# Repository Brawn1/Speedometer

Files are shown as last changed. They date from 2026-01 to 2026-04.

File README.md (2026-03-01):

# Hot Wheels Speedometer

Arduino Nano basierter Geschwindigkeitsmesser fuer Hot Wheels Strecken. Zwei IR-Sensoren im Abstand von 10 cm messen die Durchfahrtszeit und ein Servomotor zeigt die Geschwindigkeit auf einer analogen Skala an.

## Features

- Geschwindigkeitsmessung ueber zwei IR-Sensoren (10 cm Abstand)
- Analoge Tacho-Anzeige mit Servomotor
- Einstellbarer Servo-Ausschlag ueber 4 DIP-Switches (Multiplikator 1.0x - 5.0x)
- Batterieueberwachung mit Rot/Gruen LED (3.7V Li-Ion Akku)
- Sensor-Status LEDs (zeigen Sensor 1/2 Ausloesung an)
- Startup-Melodie ueber Piezo-Lautsprecher
- Serial Monitor Ausgabe fuer Debugging (9600 Baud)

## Hardware

### Komponenten

| Komponente | Anzahl |
|---|---|
| Arduino Nano | 1 |
| IR-Sensor (digital) | 2 |
| Servomotor | 1 |
| Piezo-Lautsprecher | 1 |
| 4-fach DIP-Switch | 1 |
| LED gruen (Batterie OK) | 1 |
| LED rot (Batterie niedrig) | 1 |
| LED (Sensor 1 Status) | 1 |
| LED (Sensor 2 Status) | 1 |
| Widerstand 10k Ohm | 2 |
| 3.7V Li-Ion Akku | 1 |

### Pin-Belegung

| Pin | Funktion |
|---|---|
| D2 | IR-Sensor 1 (Start) |
| D3 | IR-Sensor 2 (Ziel) |
| D4 | LED gruen (Batterie OK) |
| D5 | LED rot (Batterie niedrig) |
| D6 | LED Sensor 1 |
| D7 | LED Sensor 2 |
| D8 | Piezo-Lautsprecher |
| D9 | Servomotor |
| D10 | DIP-Switch 1 (Wert 1) |
| D11 | DIP-Switch 2 (Wert 2) |
| D12 | DIP-Switch 3 (Wert 4) |
| D13 | DIP-Switch 4 (Wert 8) |
| A0 | Batteriespannung (Spannungsteiler) |

### Spannungsteiler (Batteriemessung)

Die Batteriespannung wird ueber einen Spannungsteiler mit 2x 10k Ohm Widerstaenden gemessen. Der Spannungsteiler halbiert die Batteriespannung, damit sie im ADC-Messbereich des Arduino liegt.

```
Batterie+ ---[R1 10k]---+---[R2 10k]--- GND
                         |
                         A0
```

### DIP-Switch Anschluss

Die DIP-Switches nutzen die internen Pull-Up Widerstaende des Arduino. Jeder Schalter verbindet den Pin mit GND wenn aktiv.

```
Pin D10-D13 ---[DIP-Switch]--- GND
```

## DIP-Switch Multiplikator-Tabelle

Die 4 DIP-Switches steuern den Servo-Ausschlag mit 16 Stufen:

| DIP 4-3-2-1 | Wert | Multiplikator |
|---|---|---|
| 0000 | 0 | 1.0x |
| 0001 | 1 | 1.27x |
| 0010 | 2 | 1.53x |
| 0011 | 3 | 1.8x |
| 0100 | 4 | 2.07x |
| 0101 | 5 | 2.33x |
| 0110 | 6 | 2.6x |
| 0111 | 7 | 2.87x |
| 1000 | 8 | 3.13x |
| 1001 | 9 | 3.4x |
| 1010 | 10 | 3.67x |
| 1011 | 11 | 3.93x |
| 1100 | 12 | 4.2x |
| 1101 | 13 | 4.47x |
| 1110 | 14 | 4.73x |
| 1111 | 15 | 5.0x |

## Batterieueberwachung

| Spannung | Status | LED |
|---|---|---|
| > 3.6V | OK | Gruen |
| 3.4V - 3.6V | Niedrig | Rot |
| < 3.4V | Schwach | Rot |

Die Batterie wird alle 30 Sekunden geprueft. Die Messung erfolgt mit 16-fachem Oversampling fuer stabile Werte und wird nur durchgefuehrt wenn der Servo nicht aktiv ist.

## Messablauf

1. Einschalten: Startup-Melodie, Servo faehrt auf Startposition, Batterie wird geprueft
2. Auto faehrt durch Sensor 1: LED Sensor 1 leuchtet, Messung startet
3. Auto faehrt durch Sensor 2: LED Sensor 2 leuchtet, Geschwindigkeit wird berechnet
4. Servo zeigt Geschwindigkeit an (2 Sekunden)
5. Servo faehrt zurueck, beide Sensor-LEDs erlischen
6. Bereit fuer naechste Messung

Bei Timeout (Sensor 2 nicht innerhalb von 4 Sekunden ausgeloest) wird die Messung abgebrochen.

## Projektstruktur

```
Speedometer/
├── Code/speedometer/speedometer.ino   # Arduino Sketch
├── Kicad/                             # KiCad Schaltplan
├── Case/                              # Gehaeuse (FreeCAD)
├── LICENSE
└── README.md
```

## Lizenz

Siehe [LICENSE](LICENSE).

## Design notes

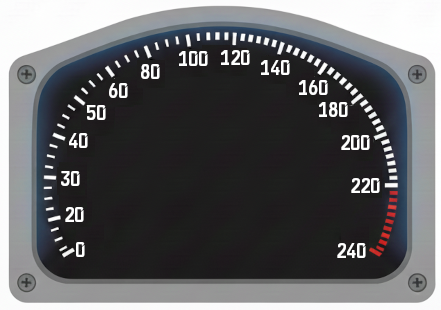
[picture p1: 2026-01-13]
Case/Tacho.png

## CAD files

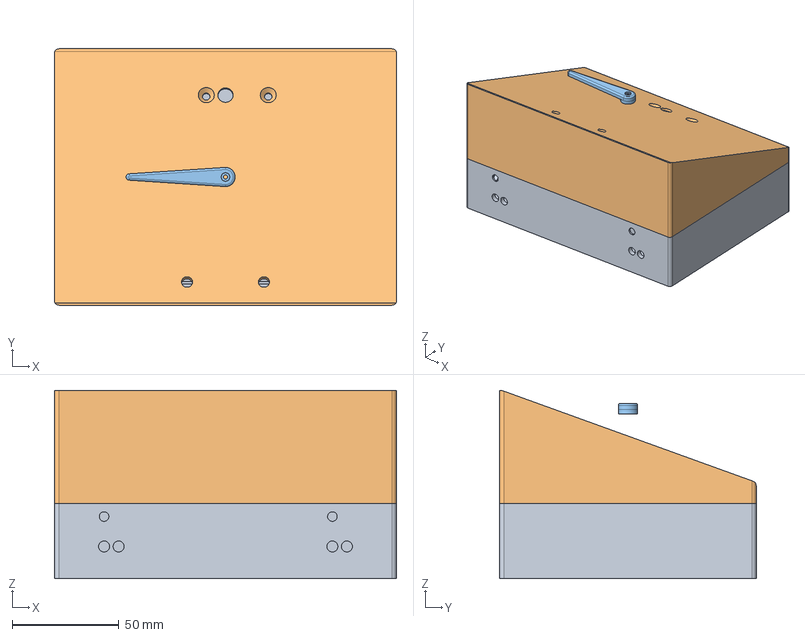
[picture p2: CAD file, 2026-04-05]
Case/speedometer.FCStd
160.0 x 120.0 x 88.0 mm
Bottom
Top
Tacho_Needle

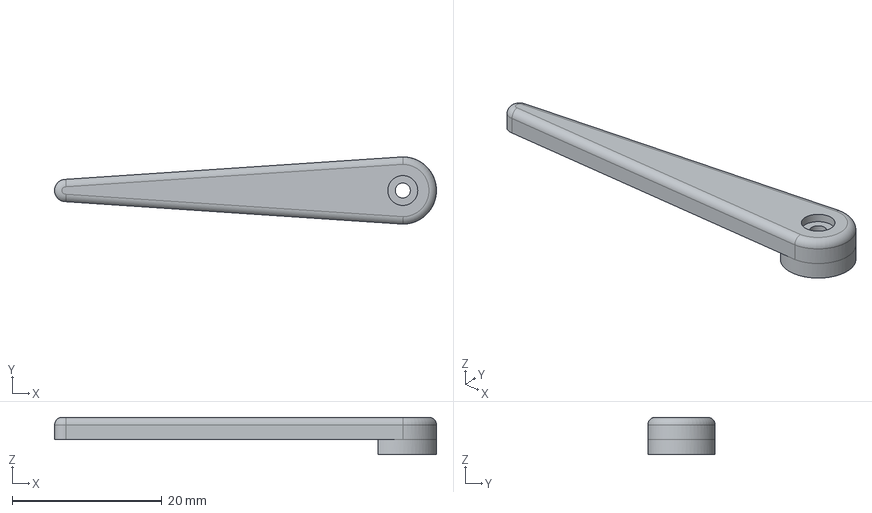
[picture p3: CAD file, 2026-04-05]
Case/Tacho_Needle.step
51.0 x 9.00 x 5.00 mm

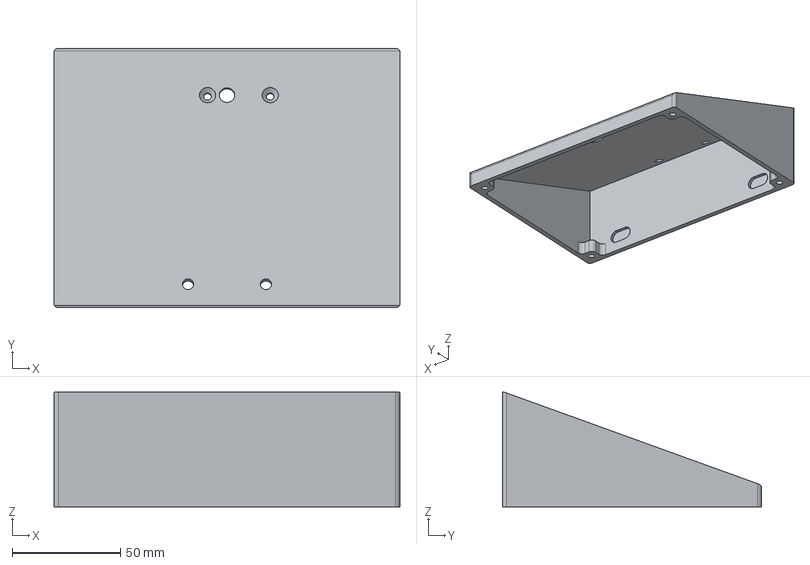
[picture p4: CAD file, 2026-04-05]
Case/Top.step
160.0 x 120.0 x 53.0 mm

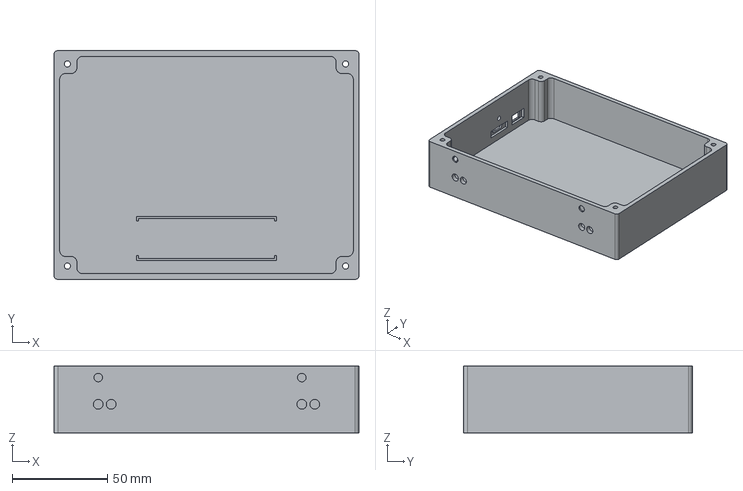
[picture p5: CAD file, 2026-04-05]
Case/Bottom.step
160.0 x 120.0 x 35.0 mm

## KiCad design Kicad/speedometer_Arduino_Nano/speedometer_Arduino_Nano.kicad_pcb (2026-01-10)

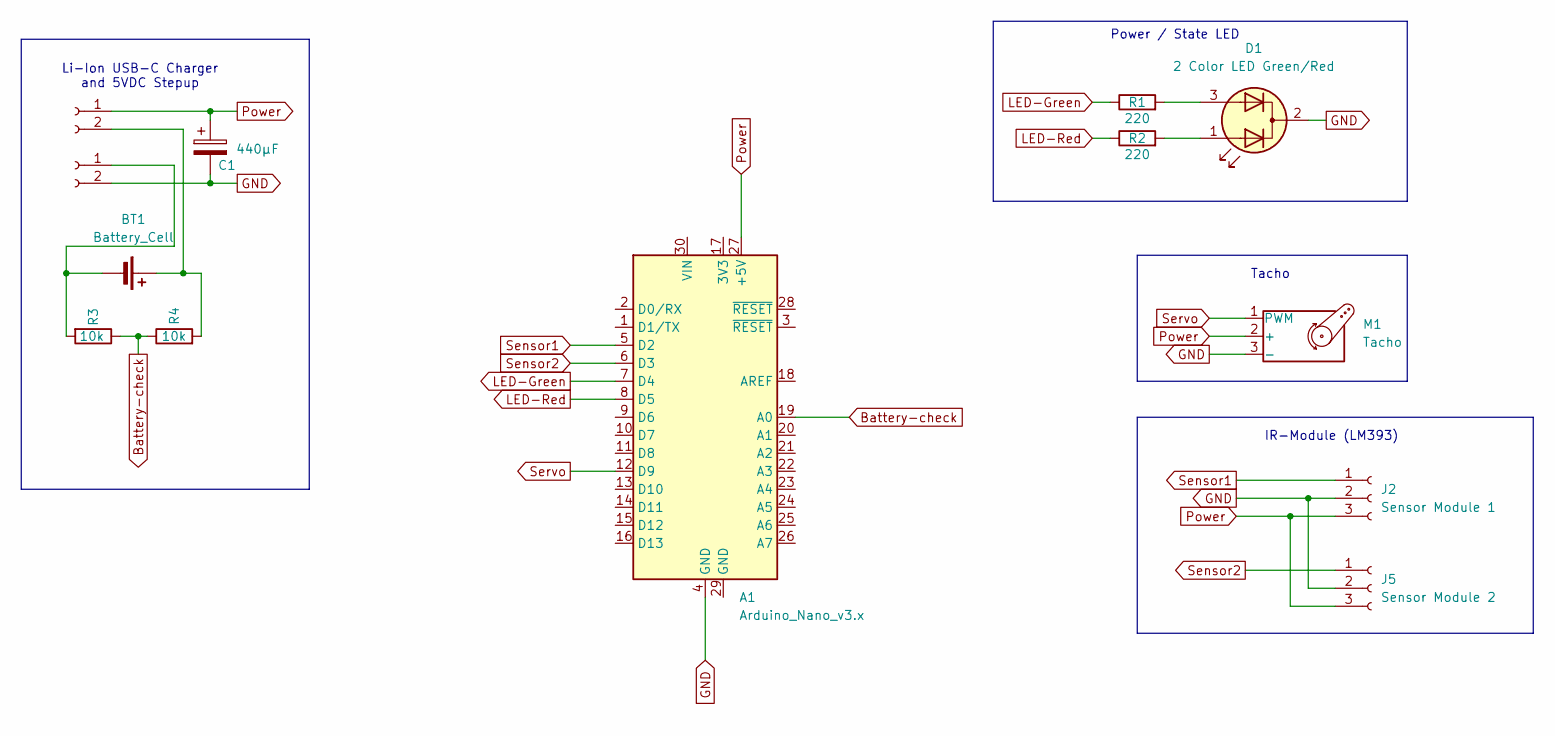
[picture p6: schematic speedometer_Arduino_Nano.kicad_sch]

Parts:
A1: Arduino_Nano_v3.x; Arduino_Nano
BT1: Battery_Cell; BatteryHolder_Keystone_1042_1x18650
C1: 440µF; CP_Radial_D10.0mm_P5.00mm
D1: 2 Color LED Green/Red; LED_D5.0mm-3
J1, J3: Conn_01x02_Socket; PinSocket_1x02_P2.54mm_Vertical
J2: Sensor Module 1; PinHeader_1x03_P2.54mm_Vertical
J5: Sensor Module 2; PinHeader_1x03_P2.54mm_Vertical
M1: Tacho; PinHeader_1x03_P2.54mm_Vertical
R1, R2: 220; R_Axial_DIN0207_L6.3mm_D2.5mm_P10.16mm_Horizontal
R3, R4: 10k; R_Axial_DIN0207_L6.3mm_D2.5mm_P10.16mm_Horizontal

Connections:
Battery-check: A1.19 (A0), R3.1, R4.1
GND: A1.4 (GND), C1.2, D1.2 (K), J2.2, J3.2, J5.2, M1.3 (-)
LED-Green: A1.7 (D4), R1.1
LED-Red: A1.8 (D5), R2.1
unnamed: BT1.1 (+), J1.2, R4.2
unnamed: BT1.2 (-), J3.1, R3.2
unnamed: D1.1 (A1), R2.2
unnamed: D1.3 (A2), R1.2
Power: A1.27 (+5V), C1.1, J1.1, J2.3, J5.3, M1.2 (+)
Sensor1: A1.5 (D2), J2.1
Sensor2: A1.6 (D3), J5.1
Servo: A1.12 (D9), M1.1 (PWM)

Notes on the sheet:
IR-Module (LM393)
Power / State LED
Tacho
Li-Ion USB-C Charger and 5VDC Stepup

Board: 2 copper layers, 13 parts (0 on the bottom side), 12 nets, no tracks yet.

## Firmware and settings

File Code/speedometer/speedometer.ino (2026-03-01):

#include <Servo.h>

// Pin-Definitionen
const int SENSOR1_PIN = 2;  // Erster IR-Sensor (Digital Pin)
const int SENSOR2_PIN = 3;  // Zweiter IR-Sensor (Digital Pin)
const int SERVO_PIN = 9;    // Servo Motor Pin
const int BATTERY_PIN = A0; // Batterie-Spannungsmessung (Analog Pin)
const int LED_GREEN_PIN = 4; // Grüne LED
const int LED_RED_PIN = 5;   // Rote LED
const int LED_SENSOR1_PIN = 6; // LED Sensor 1
const int LED_SENSOR2_PIN = 7; // LED Sensor 2
const int PIEZO_PIN = 8;      // Piezo Lautsprecher
const int DIP1_PIN = 10;      // DIP-Switch 1 (Wert 1)
const int DIP2_PIN = 11;      // DIP-Switch 2 (Wert 2)
const int DIP3_PIN = 12;      // DIP-Switch 3 (Wert 4)
const int DIP4_PIN = 13;      // DIP-Switch 4 (Wert 8)

// Konstanten
const float DISTANCE_CM = 10.0;  // Abstand zwischen Sensoren in cm
const int SERVO_MIN_ANGLE = 20;   // Minimaler Servo-Winkel
const int SERVO_MAX_ANGLE = 170; // Maximaler Servo-Winkel
const float MAX_SPEED_KMH = 150.0; // Maximale erwartete Geschwindigkeit in km/h
const int DEBOUNCE_DELAY = 50; // Entprellzeit in Millisekunden
const int SERVO_MOVE_DELAY = 500; // Zeit in ms zum Erreichen der Servo-Position
// Multiplikator-Bereich für DIP-Switches (0000=1.0, 1111=5.0)
const float MULTI_MIN = 1.0;
const float MULTI_MAX = 5.0;


// Batterie-Konstanten
const float BATTERY_LOW_VOLTAGE = 3.4;  // Warnung bei 3.4V (Li-Ion fast leer)
const float BATTERY_WARN_VOLTAGE = 3.6; // Mittlerer Bereich - LED rot
const float BATTERY_FULL_VOLTAGE = 4.2; // Voll geladen
const unsigned long BATTERY_CHECK_INTERVAL = 30000; // Batterie alle 30 Sekunden prüfen
const float ADC_REFERENCE_VOLTAGE = 4.457; // Arduino Nano ADC Referenzspannung (gemessen: 4.457V DC)
const float ADC_MAX_VALUE = 1023.0;      // 10-bit ADC maximaler Wert (0-1023)
const float R1 = 10000.0; // 10k Widerstand
const float R2 = 10000.0; // 10k Widerstand
const int ADC_SAMPLES = 16; // Anzahl Messungen für Mittelwert



// Variablen
Servo speedServo;
unsigned long sensor1Time = 0;
unsigned long sensor2Time = 0;
bool sensor1Triggered = false;
bool measurementActive = false;
unsigned long lastSensor1Trigger = 0;
unsigned long lastSensor2Trigger = 0;
unsigned long lastBatteryCheck = 0;

void setup() {
  // Serial Monitor initialisieren
  Serial.begin(9600);
  Serial.println(F("Geschwindigkeitsmessung gestartet"));
  Serial.print(F("Sensorabstand: "));
  Serial.print(DISTANCE_CM, 0);
  Serial.println(F(" cm"));
  Serial.println(F("Entprellung aktiviert"));
  Serial.println(F("Battery-Monitoring aktiviert"));
  Serial.println(F("------------------------"));
  
  // Pins konfigurieren
  pinMode(SENSOR1_PIN, INPUT);
  pinMode(SENSOR2_PIN, INPUT);
  pinMode(LED_GREEN_PIN, OUTPUT);
  pinMode(LED_RED_PIN, OUTPUT);
  pinMode(LED_SENSOR1_PIN, OUTPUT);
  pinMode(LED_SENSOR2_PIN, OUTPUT);
  pinMode(DIP1_PIN, INPUT_PULLUP);
  pinMode(DIP2_PIN, INPUT_PULLUP);
  pinMode(DIP3_PIN, INPUT_PULLUP);
  pinMode(DIP4_PIN, INPUT_PULLUP);
  
  pinMode(PIEZO_PIN, OUTPUT);

  // Startup-Melodie abspielen
  playStartupMelody();

  // Servo initialisieren und zur Startposition bewegen
  resetServoToStartPosition();

  // Erste Batterie-Prüfung
  checkBattery();
}

void loop() {
  unsigned long currentTime = millis();
  
  // Batterie regelmäßig prüfen (nur wenn Servo nicht aktiv)
  if (!measurementActive && currentTime - lastBatteryCheck > BATTERY_CHECK_INTERVAL) {
    checkBattery();
    lastBatteryCheck = currentTime;
  }

  
  // Sensor 1 prüfen (Start der Messung) mit Entprellung
  if (digitalRead(SENSOR1_PIN) == LOW && !measurementActive) {
    if (currentTime - lastSensor1Trigger > DEBOUNCE_DELAY) {
      sensor1Time = currentTime;
      sensor1Triggered = true;
      measurementActive = true;
      lastSensor1Trigger = currentTime;
      digitalWrite(LED_SENSOR1_PIN, HIGH);
      Serial.println(F("Sensor 1 ausgelöst - Messung gestartet"));
    }
  }
  
  // Sensor 2 prüfen (Ende der Messung) mit Entprellung
  if (digitalRead(SENSOR2_PIN) == LOW && measurementActive && sensor1Triggered) {
    if (currentTime - lastSensor2Trigger > DEBOUNCE_DELAY) {
      sensor2Time = currentTime;
      lastSensor2Trigger = currentTime;
      digitalWrite(LED_SENSOR2_PIN, HIGH);

      // Zeit zwischen Sensoren berechnen
      unsigned long timeDiff = sensor2Time - sensor1Time;
      
      // Geschwindigkeit berechnen
      if (timeDiff > 0) {
        // Geschwindigkeit in cm/ms
        float speedCmPerMs = DISTANCE_CM / (float)timeDiff;
        
        // Umrechnung in km/h
        // cm/ms → m/s → km/h: cm/ms * 10 * 3.6 = cm/ms * 36
        float speedKmh = speedCmPerMs * 36.0;
        
        // Umrechnung in m/s
        // cm/ms → m/s: cm/ms * (1m/100cm) * (1000ms/1s) = cm/ms * 10
        float speedMs = speedCmPerMs * 10.0;
        
        // Ergebnisse ausgeben
        Serial.println(F("------------------------"));
        Serial.print(F("Zeit: "));
        Serial.print((timeDiff / 1000.0), 4);
        Serial.println(F(" s"));
        Serial.print(F("Geschwindigkeit: "));
        Serial.print(speedKmh, 2);
        Serial.print(F(" km/h ("));
        Serial.print(speedMs, 4);
        Serial.println(F(" m/s)"));
        Serial.println(F("------------------------"));
        
        // Servo-Position berechnen und setzen
        int servoAngle = calculateServoAngle(speedKmh);
        speedServo.attach(SERVO_PIN);  // Servo aktivieren vor dem Schreiben
        speedServo.write(servoAngle);
        Serial.print(F("Servo-Position: "));
        Serial.print(servoAngle);
        Serial.print(F("° (Multiplikator: "));
        Serial.print(readDipMultiplier(), 1);
        Serial.println(F(")"));
        Serial.println();
        
        // Servo 2 Sekunden anzeigen lassen
        delay(2000);
        
        // Zurück zur Startposition fahren und Servo deaktivieren
        resetServoToStartPosition();
      }

      // Sensor-LEDs ausschalten
      digitalWrite(LED_SENSOR1_PIN, LOW);
      digitalWrite(LED_SENSOR2_PIN, LOW);

      // Reset für nächste Messung
      sensor1Triggered = false;
      measurementActive = false;
      
      // Kurze Verzögerung um Mehrfachauslösungen zu vermeiden
      delay(500);
    }
  }
  
  // Timeout: Wenn Sensor 2 nicht innerhalb von 4 Sekunden ausgelöst wird
  if (measurementActive && (currentTime - sensor1Time > 4000)) {
    Serial.println(F("Timeout - Messung abgebrochen"));
    measurementActive = false;
    sensor1Triggered = false;
    digitalWrite(LED_SENSOR1_PIN, LOW);
    digitalWrite(LED_SENSOR2_PIN, LOW);
    resetServoToStartPosition();
  }
  
  delay(1);  // Kleine Verzögerung für Stabilität
}

// Startup-Melodie abspielen
void playStartupMelody() {
  // Aufsteigende Tonfolge
  tone(PIEZO_PIN, 523, 150);  // C5
  delay(180);
  tone(PIEZO_PIN, 659, 150);  // E5
  delay(180);
  tone(PIEZO_PIN, 784, 150);  // G5
  delay(180);
  tone(PIEZO_PIN, 1047, 300); // C6
  delay(350);
  noTone(PIEZO_PIN);
}

// Funktion zum Zurücksetzen des Servos zur Startposition und Deaktivieren
void resetServoToStartPosition() {
  speedServo.attach(SERVO_PIN);
  speedServo.write(SERVO_MIN_ANGLE);
  delay(SERVO_MOVE_DELAY);  // Zeit zum Erreichen der Position
  speedServo.detach();
}

// DIP-Switch Multiplikator auslesen (LOW = aktiv wegen INPUT_PULLUP)
float readDipMultiplier() {
  int dipValue = 0;
  if (digitalRead(DIP1_PIN) == LOW) dipValue += 1;
  if (digitalRead(DIP2_PIN) == LOW) dipValue += 2;
  if (digitalRead(DIP3_PIN) == LOW) dipValue += 4;
  if (digitalRead(DIP4_PIN) == LOW) dipValue += 8;
  // 0-15 linear auf MULTI_MIN-MULTI_MAX abbilden
  return MULTI_MIN + (dipValue / 15.0) * (MULTI_MAX - MULTI_MIN);
}

// Funktion zur Berechnung des Servo-Winkels basierend auf Geschwindigkeit
int calculateServoAngle(float speedKmh) {
  // Begrenze Geschwindigkeit auf Maximum
  if (speedKmh > MAX_SPEED_KMH) {
    speedKmh = MAX_SPEED_KMH;
  }

  // Lineare Abbildung von 0-MAX_SPEED_KMH auf SERVO_MIN_ANGLE-SERVO_MAX_ANGLE
  int angle = SERVO_MIN_ANGLE + (int)((speedKmh / MAX_SPEED_KMH) * (SERVO_MAX_ANGLE - SERVO_MIN_ANGLE));

  // Begrenze Winkel auf gültigen Bereich
  if (angle < SERVO_MIN_ANGLE) angle = SERVO_MIN_ANGLE;
  if (angle > SERVO_MAX_ANGLE) angle = SERVO_MAX_ANGLE;

  float multiplier = readDipMultiplier();
  return round(float(angle) * multiplier);
}

// Funktion zur Batterie-Spannungsmessung mit Mehrfach-Sampling
float readBatteryVoltage() {
  long sum = 0;
  // Erste Messung verwerfen (ADC-Kanal stabilisieren)
  analogRead(BATTERY_PIN);
  for (int i = 0; i < ADC_SAMPLES; i++) {
    sum += analogRead(BATTERY_PIN);
  }
  float avgValue = (float)sum / ADC_SAMPLES;
  float voltage_at_pin = (avgValue / ADC_MAX_VALUE) * ADC_REFERENCE_VOLTAGE;
  return voltage_at_pin * (R1 + R2) / R2;
}

// Funktion zur Batterie-Prüfung und LED-Steuerung
void checkBattery() {
  float voltage = readBatteryVoltage();

  // Debug-Ausgabe
  Serial.print(F("Batterie: "));
  Serial.print(voltage, 2);
  Serial.print(F("V"));

  // LED-Status setzen
  if (voltage < BATTERY_LOW_VOLTAGE) {
    // Batterie schwach - Rote LED dauerhaft
    digitalWrite(LED_GREEN_PIN, LOW);
    digitalWrite(LED_RED_PIN, HIGH);
    Serial.println(F(" - BATTERIE SCHWACH!"));
  } else if (voltage < BATTERY_WARN_VOLTAGE) {
    // Batterie mittel - Rote LED
    digitalWrite(LED_GREEN_PIN, LOW);
    digitalWrite(LED_RED_PIN, HIGH);
    Serial.println(F(" - BATTERIE NIEDRIG"));
  } else {
    // Batterie OK - Grüne LED
    digitalWrite(LED_GREEN_PIN, HIGH);
    digitalWrite(LED_RED_PIN, LOW);
    Serial.println(F(" - OK"));
  }
}

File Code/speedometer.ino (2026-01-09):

#include <Servo.h>

// Pin-Definitionen
const int SENSOR1_PIN = 2;  // Erster IR-Sensor (Digital Pin)
const int SENSOR2_PIN = 3;  // Zweiter IR-Sensor (Digital Pin)
const int SERVO_PIN = 9;    // Servo Motor Pin

// Konstanten
const float DISTANCE_CM = 10.0;  // Abstand zwischen Sensoren in cm
const int SERVO_MIN_ANGLE = 0;   // Minimaler Servo-Winkel
const int SERVO_MAX_ANGLE = 180; // Maximaler Servo-Winkel
const float MAX_SPEED_KMH = 20.0; // Maximale erwartete Geschwindigkeit in km/h

// Variablen
Servo speedServo;
unsigned long sensor1Time = 0;
unsigned long sensor2Time = 0;
bool sensor1Triggered = false;
bool measurementActive = false;

void setup() {
  // Serial Monitor initialisieren
  Serial.begin(9600);
  Serial.println("Geschwindigkeitsmessung gestartet");
  Serial.println("Sensorabstand: 10cm");
  Serial.println("------------------------");
  
  // Pins konfigurieren
  pinMode(SENSOR1_PIN, INPUT);
  pinMode(SENSOR2_PIN, INPUT);
  
  // Servo initialisieren
  speedServo.attach(SERVO_PIN);
  speedServo.write(0);  // Servo auf 0° setzen
  
  delay(1000);
}

void loop() {
  // Sensor 1 prüfen (Start der Messung)
  if (digitalRead(SENSOR1_PIN) == LOW && !measurementActive) {
    sensor1Time = millis();
    sensor1Triggered = true;
    measurementActive = true;
    Serial.println("Sensor 1 ausgelöst - Messung gestartet");
  }
  
  // Sensor 2 prüfen (Ende der Messung)
  if (digitalRead(SENSOR2_PIN) == LOW && measurementActive && sensor1Triggered) {
    sensor2Time = millis();
    
    // Zeit zwischen Sensoren berechnen
    unsigned long timeDiff = sensor2Time - sensor1Time;
    
    // Geschwindigkeit berechnen
    if (timeDiff > 0) {
      // Geschwindigkeit in cm/ms
      float speedCmPerMs = DISTANCE_CM / (float)timeDiff;
      
      // Umrechnung in km/h
      float speedKmh = speedCmPerMs * 3600.0;
      
      // Umrechnung in m/s
      float speedMs = speedCmPerMs * 10.0;
      
      // Ergebnisse ausgeben
      Serial.println("------------------------");
      Serial.print("Zeit: ");
      Serial.print(timeDiff);
      Serial.println(" ms");
      Serial.print("Geschwindigkeit: ");
      Serial.print(speedKmh, 2);
      Serial.print(" km/h (");
      Serial.print(speedMs, 2);
      Serial.println(" m/s)");
      Serial.println("------------------------");
      
      // Servo-Position berechnen und setzen
      int servoAngle = calculateServoAngle(speedKmh);
      speedServo.write(servoAngle);
      Serial.print("Servo-Position: ");
      Serial.print(servoAngle);
      Serial.println("°");
      Serial.println();
    }
    
    // Reset für nächste Messung
    sensor1Triggered = false;
    measurementActive = false;
    
    // Kurze Verzögerung um Mehrfachauslösungen zu vermeiden
    delay(1000);
    
    // Servo zurücksetzen
    speedServo.write(0);
  }
  
  // Timeout: Wenn Sensor 2 nicht innerhalb von 5 Sekunden ausgelöst wird
  if (measurementActive && (millis() - sensor1Time > 5000)) {
    Serial.println("Timeout - Messung abgebrochen");
    measurementActive = false;
    sensor1Triggered = false;
    speedServo.write(0);
  }
  
  delay(10);  // Kleine Verzögerung für Stabilität
}

// Funktion zur Berechnung des Servo-Winkels basierend auf Geschwindigkeit
int calculateServoAngle(float speedKmh) {
  // Begrenze Geschwindigkeit auf Maximum
  if (speedKmh > MAX_SPEED_KMH) {
    speedKmh = MAX_SPEED_KMH;
  }
  
  // Lineare Abbildung von 0-MAX_SPEED_KMH auf 0-180°
  int angle = (int)((speedKmh / MAX_SPEED_KMH) * SERVO_MAX_ANGLE);
  
  // Begrenze Winkel auf gültigen Bereich
  if (angle < SERVO_MIN_ANGLE) angle = SERVO_MIN_ANGLE;
  if (angle > SERVO_MAX_ANGLE) angle = SERVO_MAX_ANGLE;
  
  return angle;
}

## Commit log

2026-01-09 Add Arduino speed measurement code with IR sensors and servo display
2026-01-09 patched on arduino uno
2026-01-09 update servo
2026-01-09 Add debouncing to prevent false sensor triggers from servo noise
    [speedometer.ino]
2026-01-09 Add battery monitoring with 2-color LED indicator (Green/Red)
2026-01-09 move print string from RAM to Flash
2026-01-10 removed cache and backups
    [speedometer_Arduino_Nano.kicad_pcb, speedometer_Arduino_Nano.kicad_sch]
2026-01-10 added Case Version 0.1
    [Tacho_Needle.stl, speedometer-Bottom.stl, speedometer-Top.stl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]
2026-01-11 Removed Rounding on bottom
    [speedometer-Bottom.stl, speedometer-Top.stl, speedometer.FCStd]
2026-01-12 Optimize servo power management to reduce current consumption
2026-01-12 Refactor: Extract servo reset logic into helper function
    [speedometer.ino]
2026-01-12 Use constants for servo angles and delays for better maintainability
2026-01-12 Fix incorrect speed conversion formulas from cm/ms to km/h and m/s
    [speedometer.ino]
2026-01-13 Add documentation and constants for battery voltage calculation
    - Added ADC_REFERENCE_VOLTAGE constant (5.0V) to clarify Arduino reference voltage
    - Added VOLTAGE_DIVIDER_RATIO constant (2.0) to document voltage divider configuration
    - Added ADC_MAX_VALUE constant (1023.0) for 10-bit ADC
    - Enhanced comments in checkBattery() to explain each step of the voltage calculation
    - Replaced magic numbers with named constants for better code maintainability
    The calculation (sensorValue / 1023.0) * 5.0 * 2.0 is correct:
    1. Normalize ADC reading to 0.0-1.0
    2. Multiply by 5V reference voltage to get voltage at ADC pin
    3. Multiply by 2 to compensate for voltage divider (2x 10kΩ resistors divide by 2)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
    [speedometer.ino]
2026-01-13 Update ADC reference voltage to measured value of 4.457V
    The Arduino Nano is running at 4.457V DC (not 5V), which affects the ADC reference voltage. Updated the ADC_REFERENCE_VOLTAGE constant from 5.0 to 4.457 to match the actual measured voltage for accur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
2026-03-01 erweiterung Readme.md code
    [speedometer.FCStd, speedometer_Arduino_Nano.kicad_sch]
2026-04-05 case v2
    [Bottom.step, Tacho_Needle.step, Tacho_Needle.stl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]
